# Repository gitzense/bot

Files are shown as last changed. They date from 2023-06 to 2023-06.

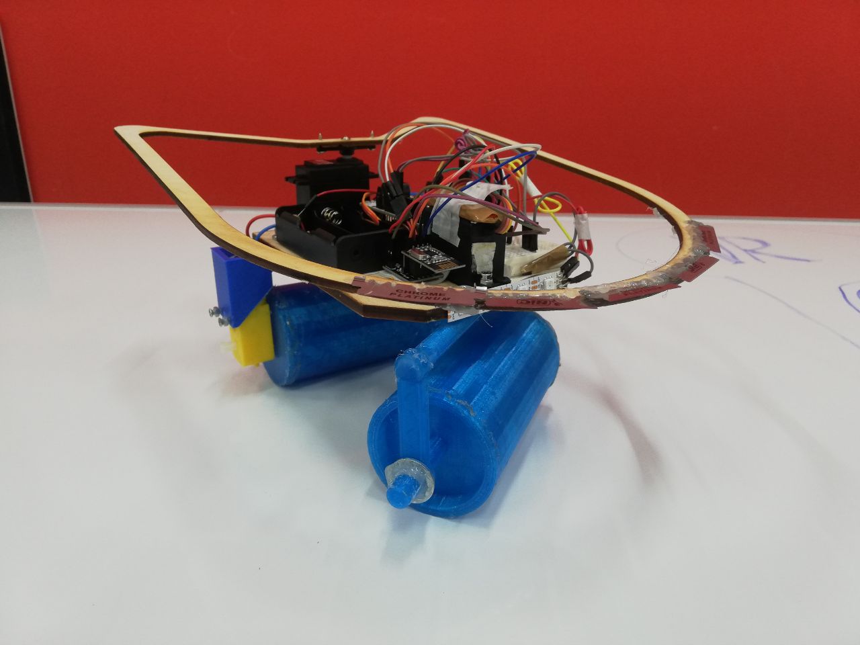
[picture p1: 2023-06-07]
photos and videos/bot_7.jpg

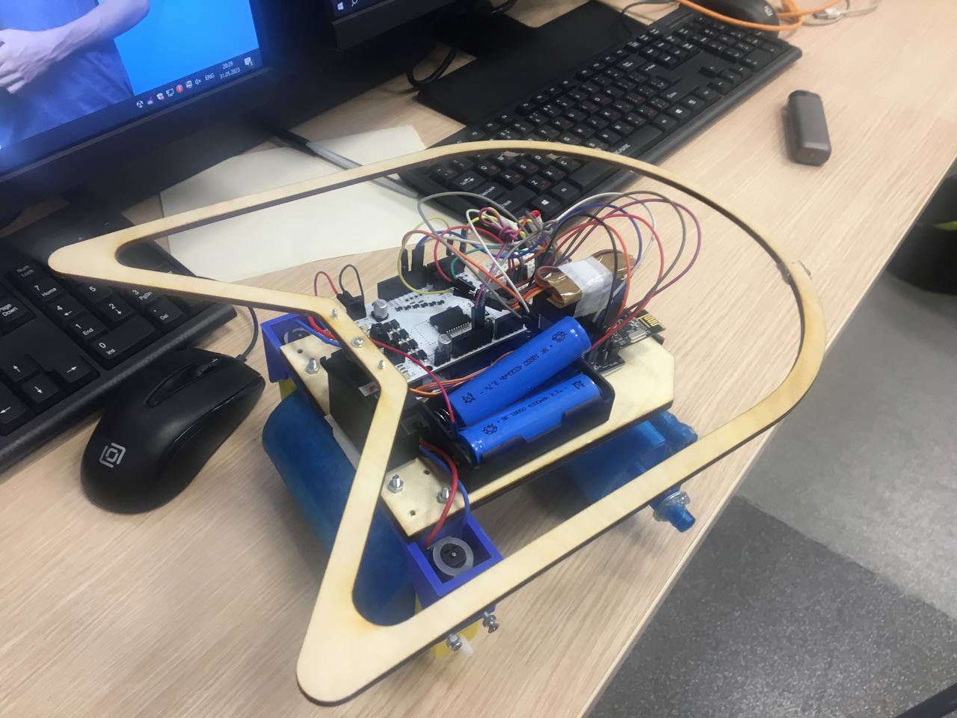
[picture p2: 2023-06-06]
photos and videos/bot_3.jpg

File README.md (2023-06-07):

# Робот на ардуино
Бот был протестирован на трассе. Время прохождения трассы - 1 минута 34 секунды. Пройдены 4/4 испытаний.

track

Робот на Arduino Leonardo с радиомодулем NRF24. Для лучшего сцепления с гладкой поверхностью на ходовые валки был нанесен термоклей вдоль оси движение в небольшом количестве.

bot_6

В роботе использовалось:
- Motor Shield,
- Arduino Leonardo/Amperka Iskra Neo,
- NRF,
- NRF+,
- акумуляторы 18650 x2,
- DC motor x2,
- RGB LED лента (4 светодиода),
- servo 180 x2.

https://github.com/gitzense/bot/assets/114235388/fd15c5e6-877d-4c51-bf17-9566ea2b325a

Для контроллера использовалась плата Arduino Pro Micro. Джойствик отвечал за движение по оси Y, потенциометр управлял сервоприводом для поворота, кнопка отвечала за движение сервопривода с режущей насадкой. 

controller

В контроллере использовалось:
- Arduino Pro Micro,
- NRF,
- NRF+,
- повербанк,
- потенциометр,
- кнопка,
- джойстик.

https://github.com/gitzense/bot/assets/114235388/252602ba-0840-4733-84bb-086d04a6e93f

Использованные библиотеки:
- Servo by Michael Margolis (управление сервоприводами),
- Adafruit NeoPixel by Adafruit (настройка светодиодной ленты),
- RF24 by TMRh20 (управление радиомодулем).

1. Код для контроллера:

``` c++
#include <SPI.h>
#include <nRF24L01.h>
#include <RF24.h>

#define VX_PIN A0
#define VY_PIN A1
#define BTN_PIN 2

RF24 radio(9, 10);
int data[3];

void setup() {

  Serial.begin(9600);
  radio.begin();
  radio.setChannel(2);
  radio.setDataRate(RF24_1MBPS);
  radio.setPALevel(RF24_PA_HIGH);
  radio.openWritingPipe(0x1234567890LL);
  radio.stopListening();
  
  pinMode(BTN_PIN, INPUT);
  
}

void loop() {

  data[0] = analogRead(VX_PIN);
  data[1] = analogRead(VY_PIN);
  data[2] = digitalRead(BTN_PIN);

  radio.write(&data, sizeof(data));
  delay(15);
  
}
```

2. Код для робота:

``` c++
#include <SPI.h>
#include <nRF24L01.h>
#include <RF24.h>

#include <Adafruit_NeoPixel.h>

#include <Servo.h>
Servo myservo;
Servo myservo2;

#define SPEED_1 5 
#define DIR_1 4

#define SPEED_2 6
#define DIR_2 7

#define MATRIX_PIN    0
#define LED_COUNT 4

Adafruit_NeoPixel matrix = Adafruit_NeoPixel(LED_COUNT, MATRIX_PIN, NEO_GRB + NEO_KHZ800);

RF24 radio(9, 10);
int data[3];

int pos = 15;

void setup() {
  
  Serial.begin(9600);
  myservo.attach(3);
  myservo2.attach(12);
  matrix.begin();
  radio.begin();
  radio.setChannel(2);
  radio.setDataRate(RF24_1MBPS);
  radio.setPALevel(RF24_PA_HIGH);
  radio.openReadingPipe(0, 0x1234567890LL);
  radio.startListening();

  for (int i = 4; i < 8; i++) {     
    pinMode(i, OUTPUT);
  }
  
}

void loop() { 
  
  if (radio.available()) {
    radio.read(&data, sizeof(data));

    for (int i = 0; i < matrix.numPixels(); i++) {
      matrix.setPixelColor(i, 255, 255, 255);
      matrix.show();  
    }

    int servoPosition = map(data[0], 0, 1023, 0, 180);
    myservo.write(servoPosition);

    if (data[2] == 1) {
      myservo2.write(45);
      pos = 15;
    }  
    else if (data[2] == 0) {
      myservo2.write(pos);
      pos += 1;
      if (pos == 75) {
        pos = 15;
      }
    }
    if (data[1] < 200) {
      digitalWrite(DIR_1, HIGH);
      digitalWrite(DIR_2, HIGH);
      analogWrite(SPEED_1, 220);
      // analogWrite(SPEED_2, 220);
     }
    else if (data[1] > 900) {
      digitalWrite(DIR_1, LOW);
      digitalWrite(DIR_2, LOW);
      analogWrite(SPEED_1, 255);
      analogWrite(SPEED_2, 255);
    }
    else {
      digitalWrite(DIR_1, HIGH);
      digitalWrite(DIR_2, LOW);
      analogWrite(SPEED_1, 0);
      analogWrite(SPEED_2, 0);      
    }
  }
  
}
```

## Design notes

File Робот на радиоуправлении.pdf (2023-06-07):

МИНИСТЕРСТВО ОБРАЗОВАНИЯ И НАУКИ РОССИЙСКОЙ ФЕДЕРАЦИИ

ФЕДЕРАЛЬНОЕ ГОСУДАРСТВЕННОЕ АВТОНОМНОЕ УЧРЕЖДЕНИЕ ВЫСШЕГО ОБРАЗОВАНИЯ

«Национальный исследовательский технологический

университет «МИСиС»

ИНСТИТУТ | ЭКОТЕХНОЛОГИЙ И ИНЖИНИРИНГА
КАФЕДРА | МЕТАЛЛОВЕДЕНИЕ ЦВЕТНЫХ МЕТАЛЛОВ
НАПРАВЛЕНИЕ | 15.04.02 Технологические машины и оборудование

Практика цифрового производства

на тему: “Робот на радиоуправлении”

Студент: Фролов Н.В.

Группа: МТМО-22-3

Проверил: Тавитов А.Г.

Москва 2023

Содержание

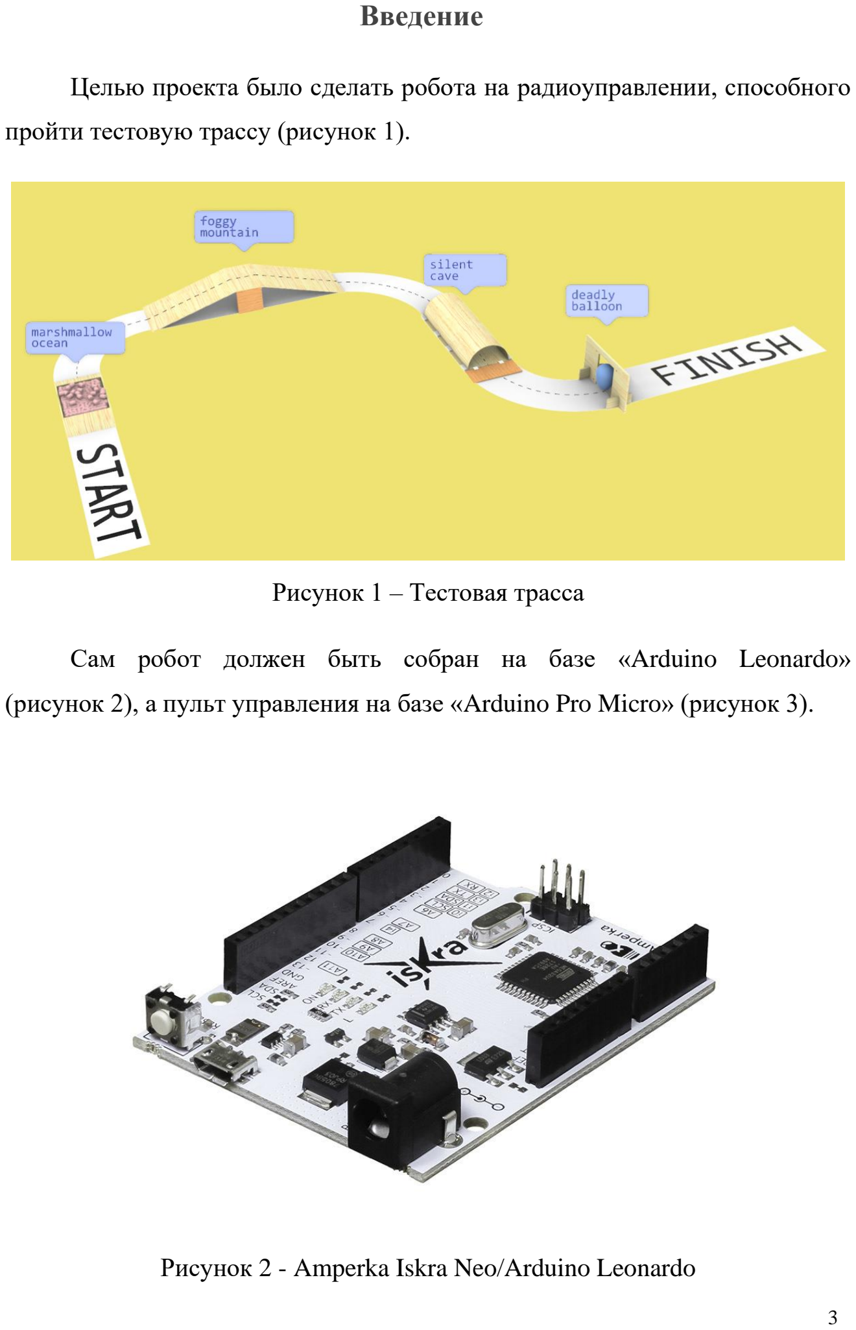
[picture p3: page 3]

Введение

Целью проекта было сделать робота на радиоуправлении, способного

пройти тестовую трассу (рисунок 1).

Рисунок 1 – Тестовая трасса

Сам робот должен быть собран на базе «Arduino Leonardo»

(рисунок 2), а пульт управления на базе «Arduino Pro Micro» (рисунок 3).

Рисунок 2 - Amperka Iskra Neo/Arduino Leonardo

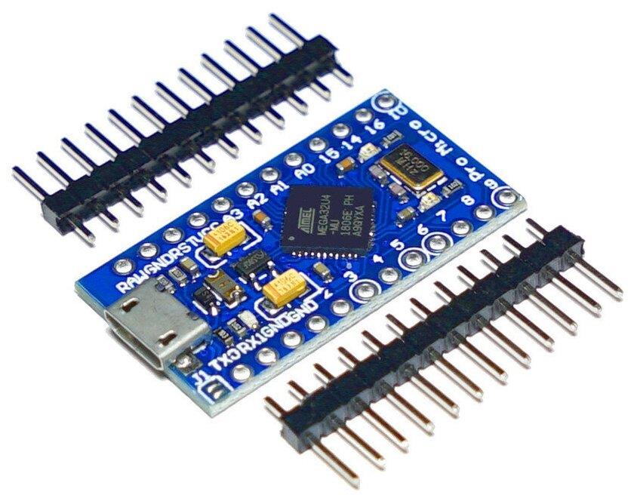
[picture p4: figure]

Рисунок 3 - Arduino Pro Micro

Дополнительным условием было: «робот должен передвигаться не на

колесах».

### 1 Работа над роботом

### 1.1 Компоненты

Изначально были даны следующие компоненты:

- Arduino Leonardo/Amperka Iskra Neo,
- Motor Shield,
- NRF,
- NRF+,
- Аккумуляторы 18650 x2,
- DC motor x2,
- RGB LED лента (4 светодиода),
- Servo 180 x2.

### 1.2 Проектирование и печать

Было принято решение, что робот будет передвигаться при помощи

двух валков, референсом был дорожный каток (рисунок 4).

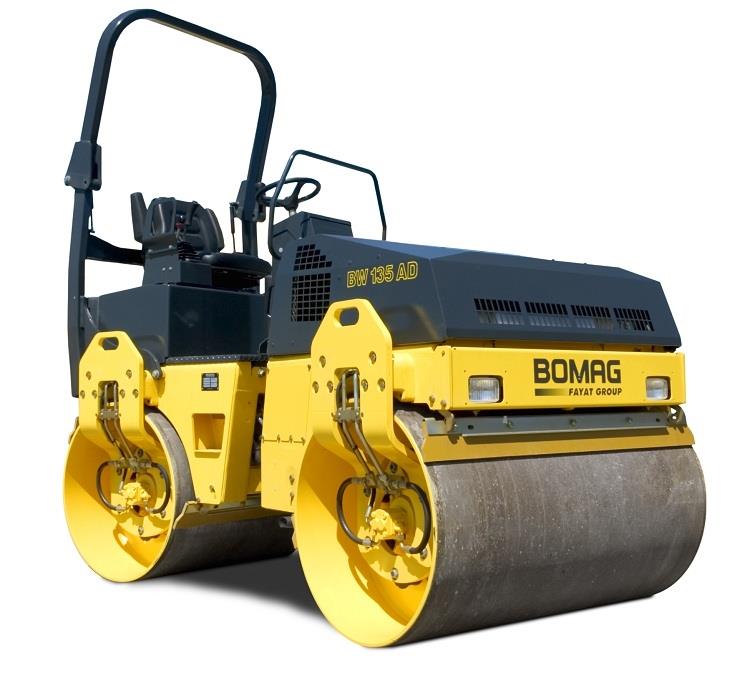
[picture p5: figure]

Рисунок 4 – Дорожный каток

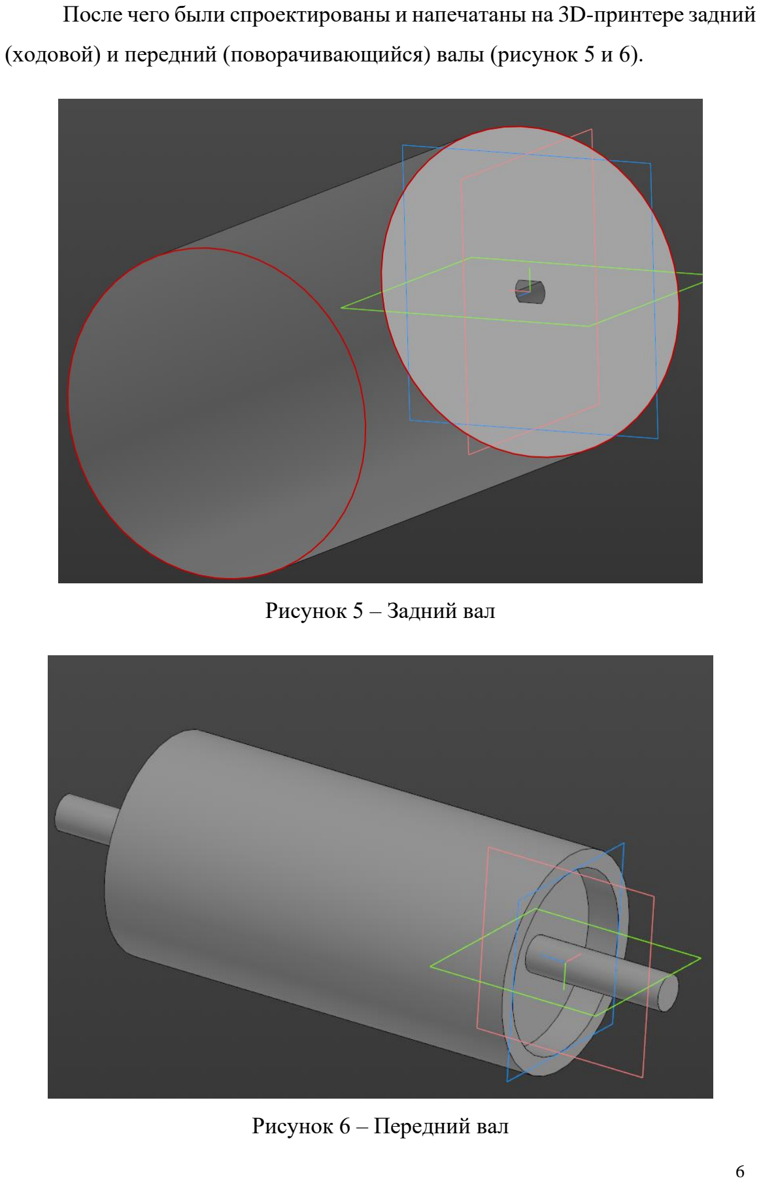
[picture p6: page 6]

После чего были спроектированы и напечатаны на 3D-принтере задний

(ходовой) и передний (поворачивающийся) валы (рисунок 5 и 6).

Рисунок 5 – Задний вал

Рисунок 6 – Передний вал

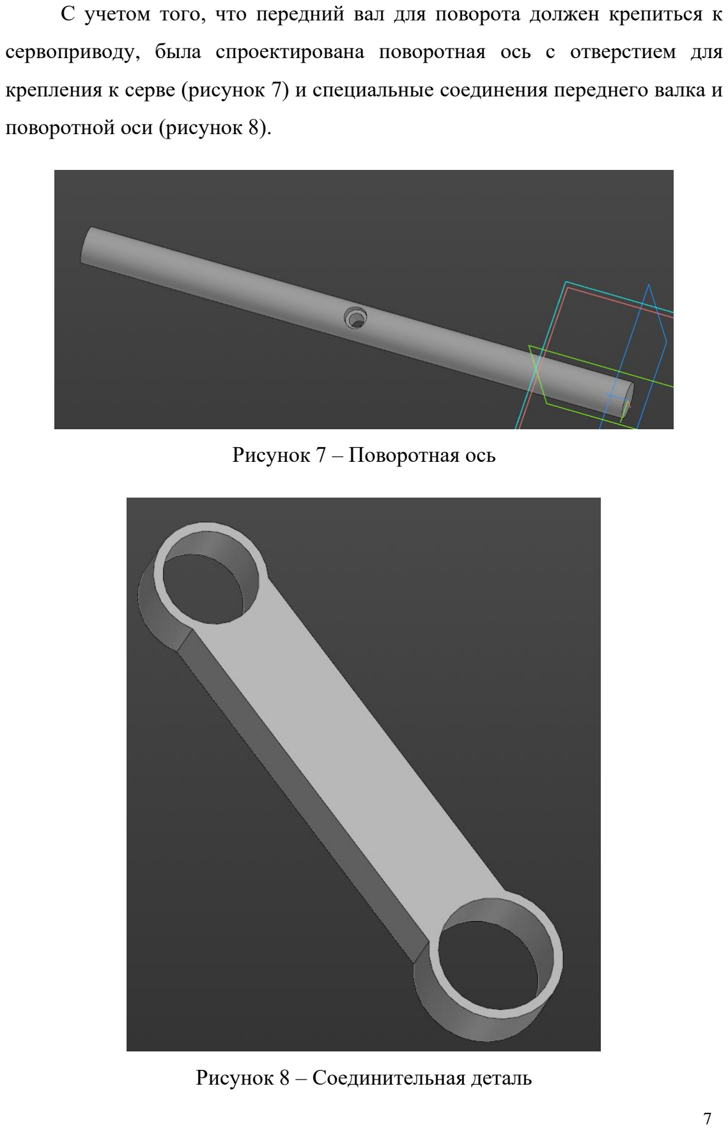
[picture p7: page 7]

С учетом того, что передний вал для поворота должен крепиться к

сервоприводу, была спроектирована поворотная ось с отверстием для

крепления к серве (рисунок 7) и специальные соединения переднего валка и

поворотной оси (рисунок 8).

Рисунок 7 – Поворотная ось

Рисунок 8 – Соединительная деталь

Для крепления моторов к роботу были спроектированы и напечатаны

кронштейны (рисунок 9).

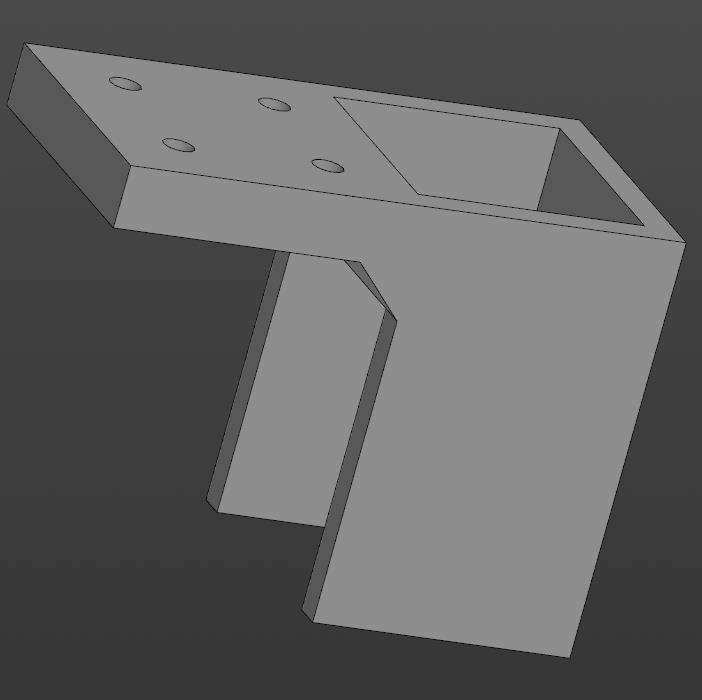
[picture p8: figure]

Рисунок 9 - Кронштейн

### 1.3 Лазерная резка

Было принято решение, что основа робота, на которой будут

закреплены все элементы, не должна быть слишком громоздкой. В связи с

этим, габариты основы подбирались так, чтобы все компоненты сидели

почти вплотную. Сама основа в дальнейшем была вырезана на лазерном

станке (рисунок 10).

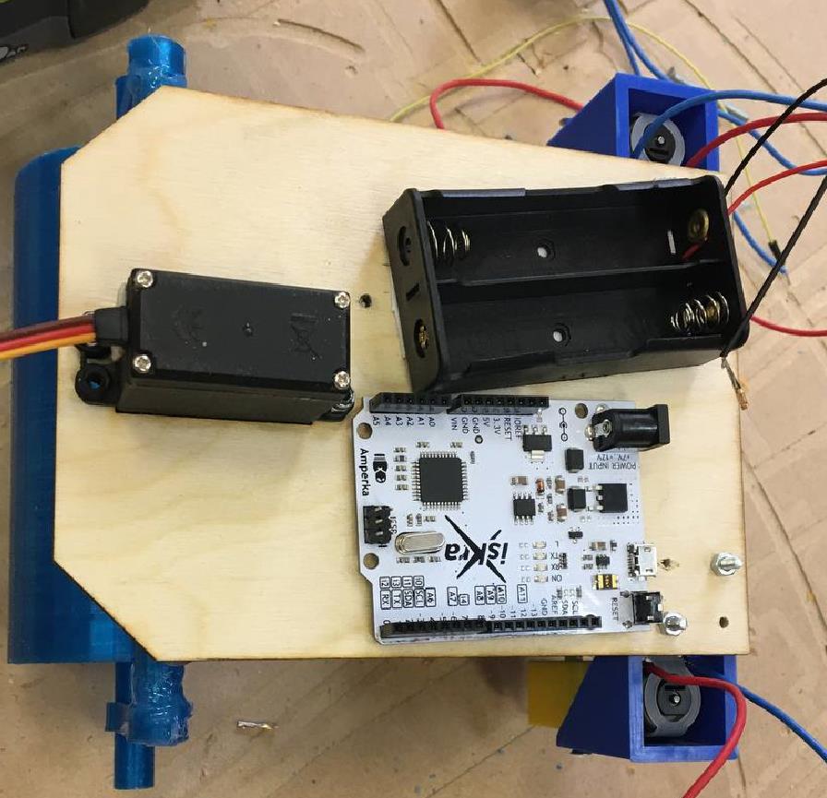
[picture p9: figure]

Рисунок 10 – Установленная основа

Так как на тестовой трассе необходимо лопнуть шарик, дополнительно

была сделана деталь (рисунок 11), на которой в дальнейшем были

закреплены лезвия. Габариты детали выбирались исходя из основы робота,

режущая часть должна выступать вперед более чем на 50 мм. Весь

получившийся «резак» был закреплен на сервоприводе.

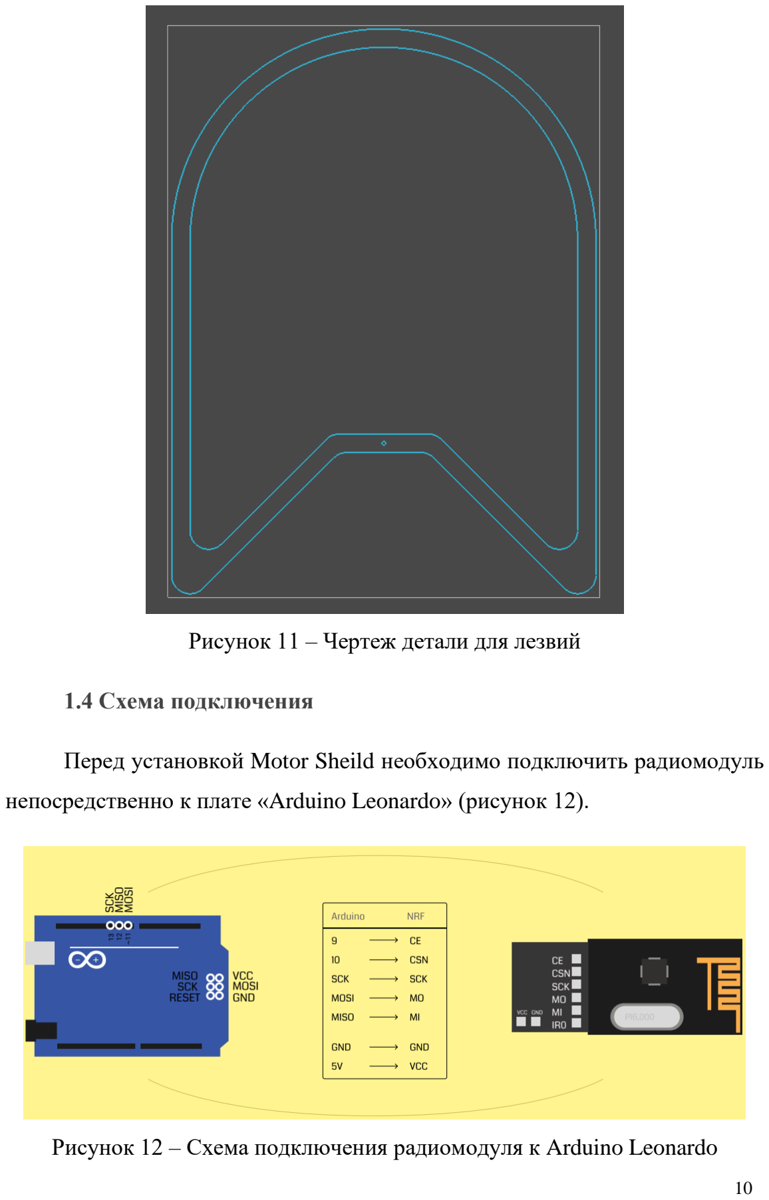
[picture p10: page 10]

Рисунок 11 – Чертеж детали для лезвий

### 1.4 Схема подключения

Перед установкой Motor Sheild необходимо подключить радиомодуль

непосредственно к плате «Arduino Leonardo» (рисунок 12).

Рисунок 12 – Схема подключения радиомодуля к Arduino Leonardo

Затем на плату устанавливается Motor Sheild, и через breadboard все

компоненты подключаются к связке «motor shield-плата» (рисунок 13).

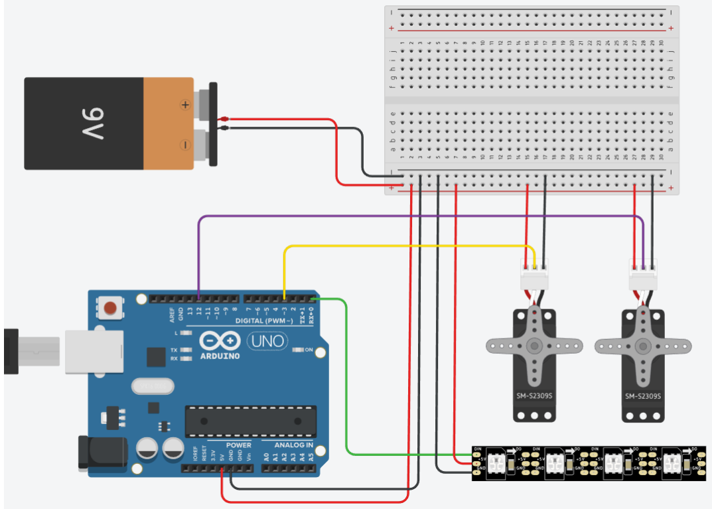
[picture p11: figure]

Рисунок 13 – Схема подключения компонентов к роботу

### 2 Работа над пультом управления

### 2.1 Компоненты

- Arduino Pro Micro,
- Потенциометр,
- NRF,
- NRF+,
- Кнопка,
- Джойстик.

### 2.2 Лазерная резка

Для удобства использования всех компонентов, была вырезана основа

пульта (рисунок 14), на которой были закреплены все элементы управления

(рисунок 15).

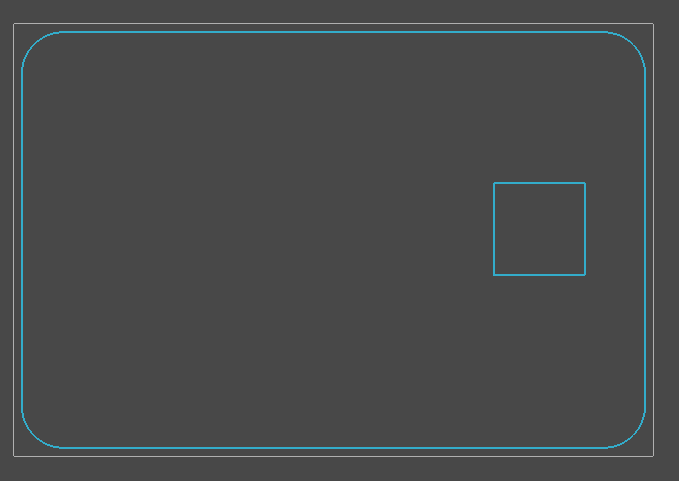
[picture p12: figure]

Рисунок 14 – Чертеж основы для пульта управления

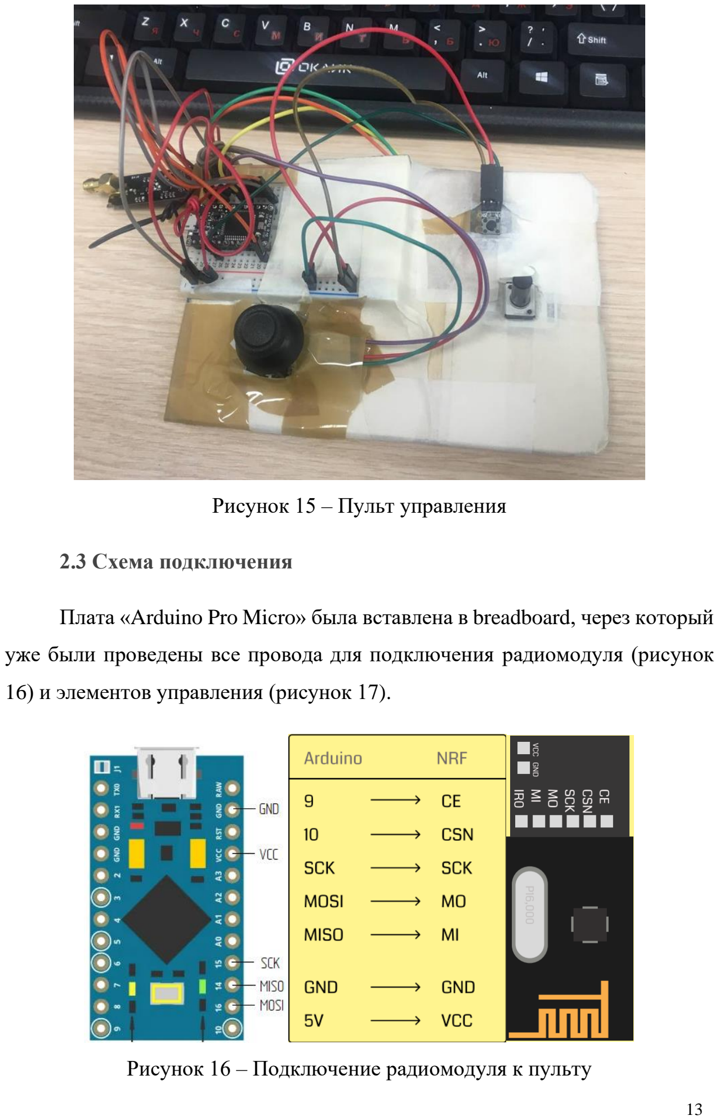
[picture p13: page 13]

Рисунок 15 – Пульт управления

### 2.3 Схема подключения

Плата «Arduino Pro Micro» была вставлена в breadboard, через который

уже были проведены все провода для подключения радиомодуля (рисунок

16) и элементов управления (рисунок 17).

Рисунок 16 – Подключение радиомодуля к пульту

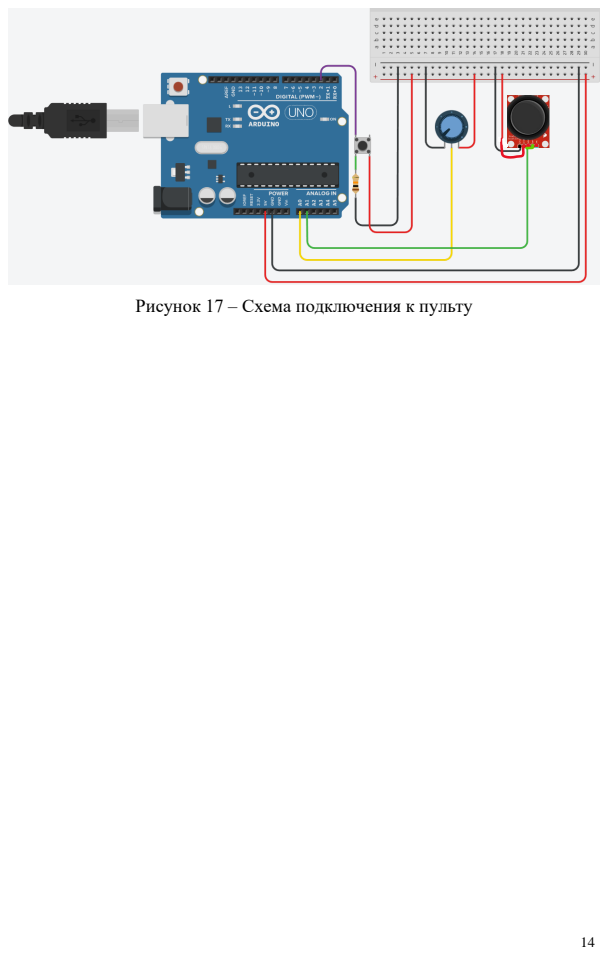
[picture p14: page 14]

Рисунок 17 – Схема подключения к пульту

### 3 Код

Для управления был написан код для основной платы робота:

приемника (рисунок 18) и для пульта управления: передатчика

(рисунок 19).

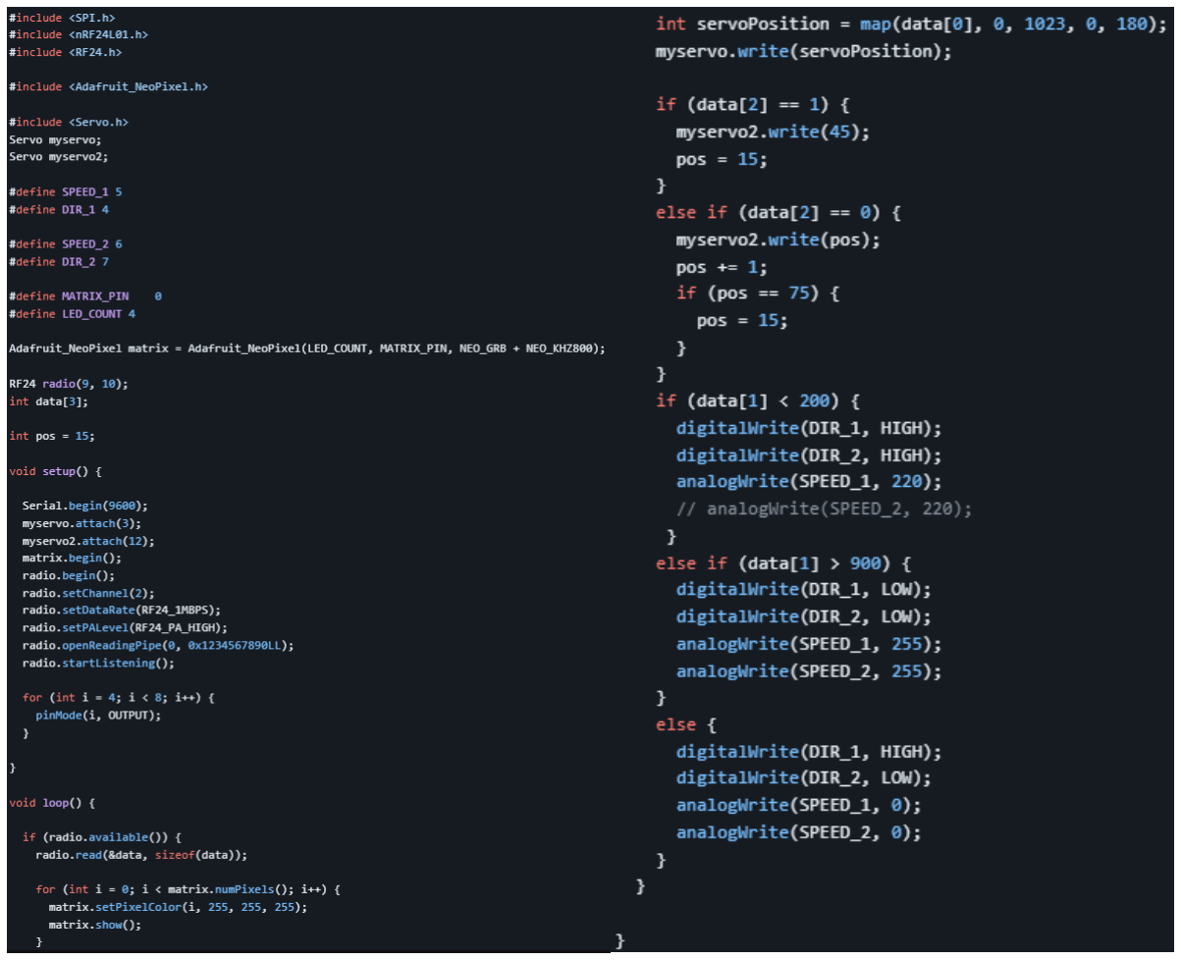
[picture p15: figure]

Рисунок 18 – Код для приемника

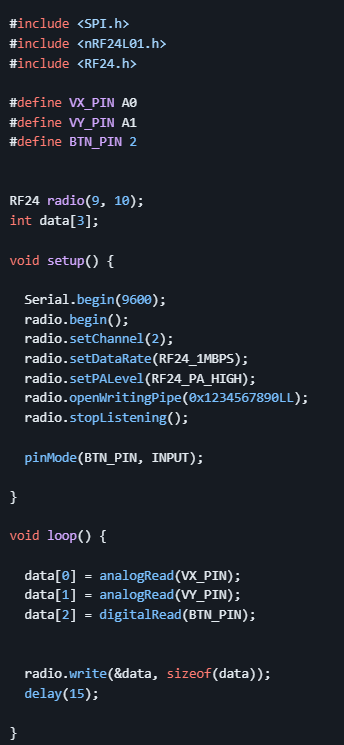
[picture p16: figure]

Рисунок 19 – Код для передатчика

### 4 Проблемы и решения

Первой проблемой стал «гуляющий» передний валок при повороте.

Эта проблема возникла из-за особенности соединения валка и поворотной

оси. Поскольку нижнее отверстие соединения должно быть большего

диаметра, чтобы валок мог крутиться, из-за этого же сам вал при повороте

иногда проскальзывал по этому отверстию.

Несмотря на то, что эта проблема никак не сказывалась на

работоспособности, возникли опасения, что при резком повороте может

повредиться либо само соединение, либо сервопривод, поэтому было

принято решение ограничить движение валка в отверстии соединения

шайбами (рисунок 20).

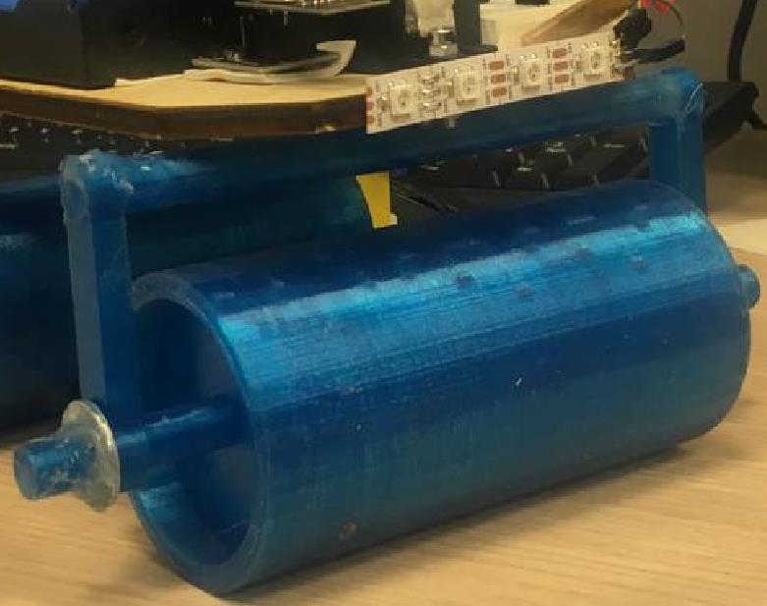
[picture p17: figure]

Рисунок 20 – Решение первой проблемы

Второй проблемой стали стенки кронштейнов. Они терлись о ходовой

валок, потому было принято решение их подрезать (рисунок 21).

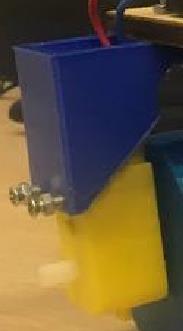
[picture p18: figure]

Рисунок 21 – Решение второй проблемы

Третья проблема – плохо прилегающий «плюс» в аккумуляторном

блоке, поэтому плюс проведен отдельным проводом (рисунок 22).

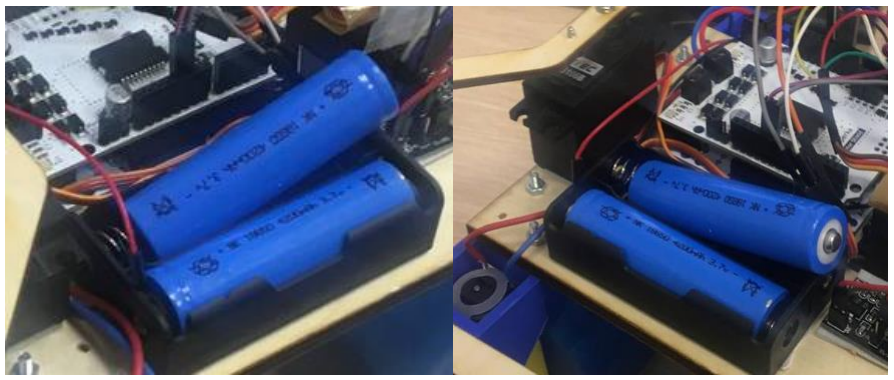
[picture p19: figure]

Рисунок 22 – Решение третьей проблемы

Четвертая проблема состояла в том, что элементы управления плохо

садились на стяжки, в связи с этим все было закреплено на скотч и ленту

(см. рисунок 15).

Последняя проблема обнаружилась при тренировочном прохождении

трассы – валки слишком гладкие и им не хватало сцепления для подъема в

горку. Чтобы решить эту проблему на валки был нанесен термоклей в

небольшом количестве вдоль оси движения. Сцепление на горке

улучшилось, но скорость на обычном покрытии сильно упала, что

неприятно, но не столь критично.

Заключение

В ходе выполнения проекта были спроектированы и сделаны

необходимые для робота детали, написан код для управления роботом,

сделан пульт управления.

Робот был собран и протестирован перед заездом. Передача сигнала и

все заложенные функции работают.

Тестовую трассу робот полностью прошел.

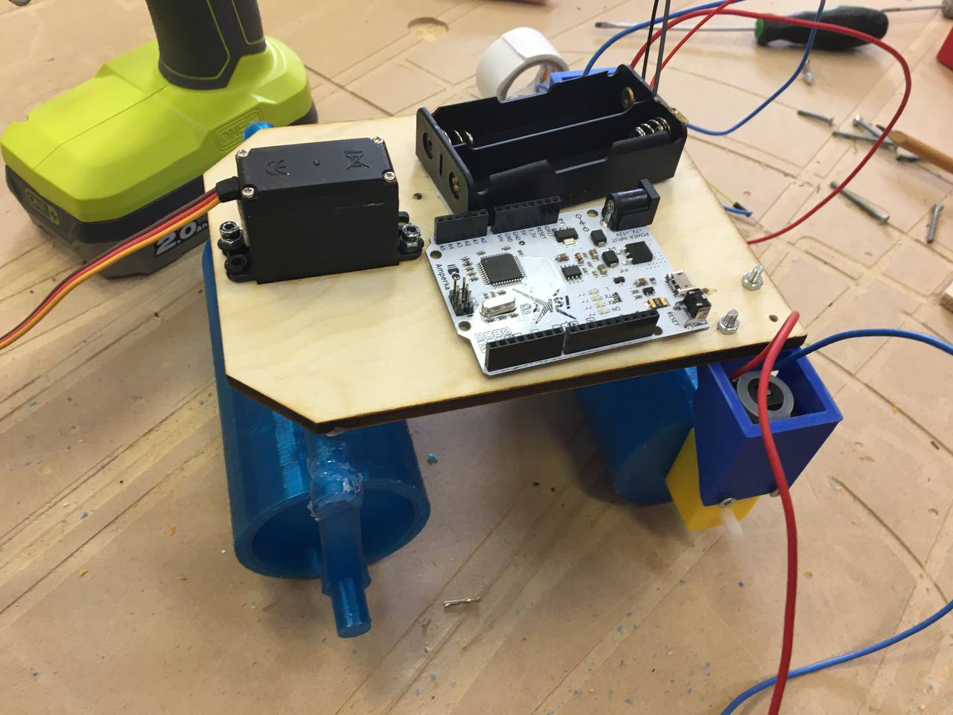
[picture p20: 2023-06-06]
photos and videos/bot_in_progress_1.jpg

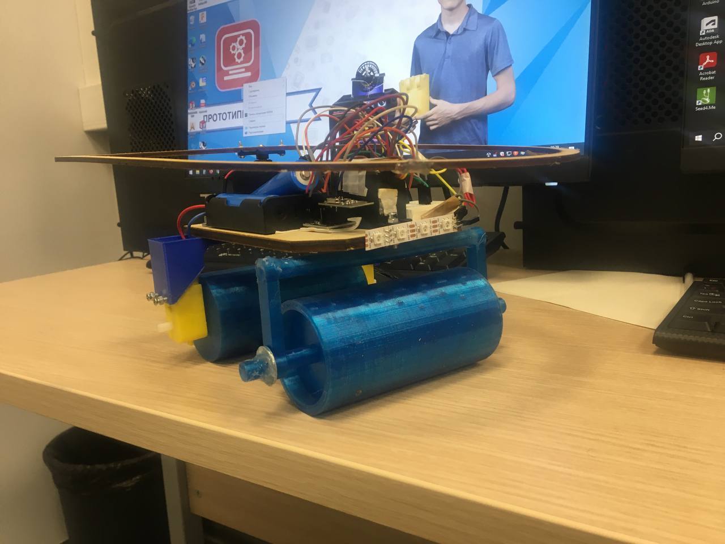
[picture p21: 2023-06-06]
photos and videos/bot_1.jpg

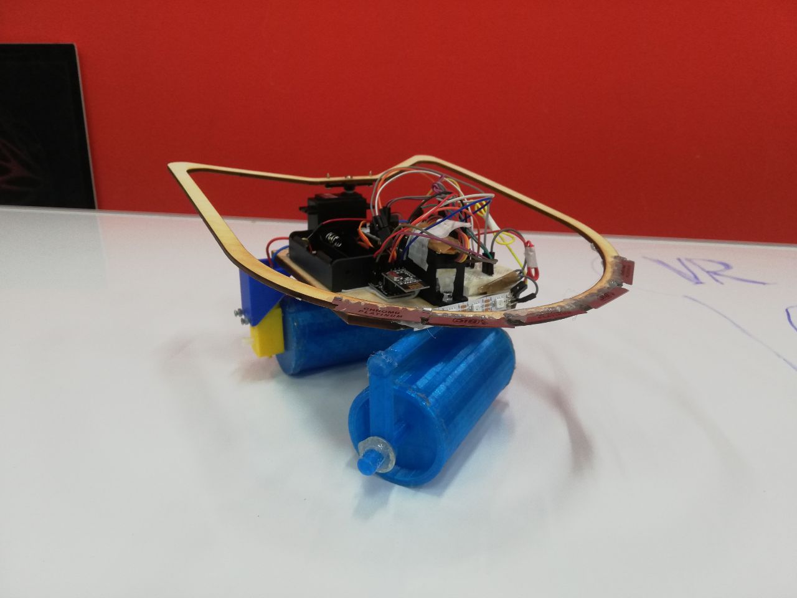
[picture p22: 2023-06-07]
photos and videos/bot_5.jpg

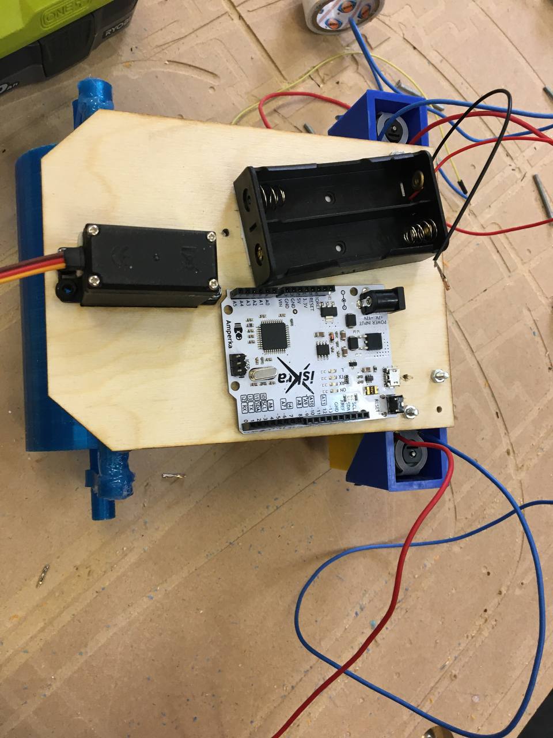
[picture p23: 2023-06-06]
photos and videos/bot_in_progress_2.jpg

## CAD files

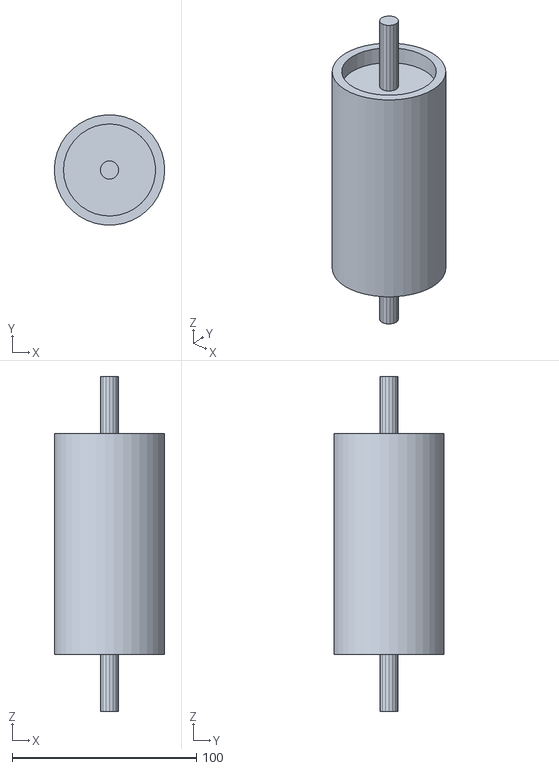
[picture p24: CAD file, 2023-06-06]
STL/front shaft.stl
60.0 x 59.8 x 182.0

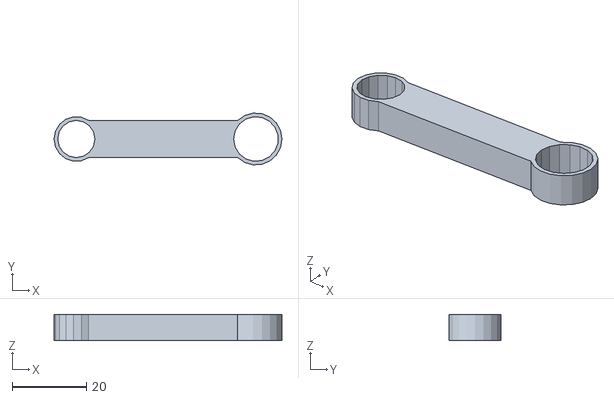
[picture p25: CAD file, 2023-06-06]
STL/shafts connector.stl
61.3 x 13.9 x 7.00

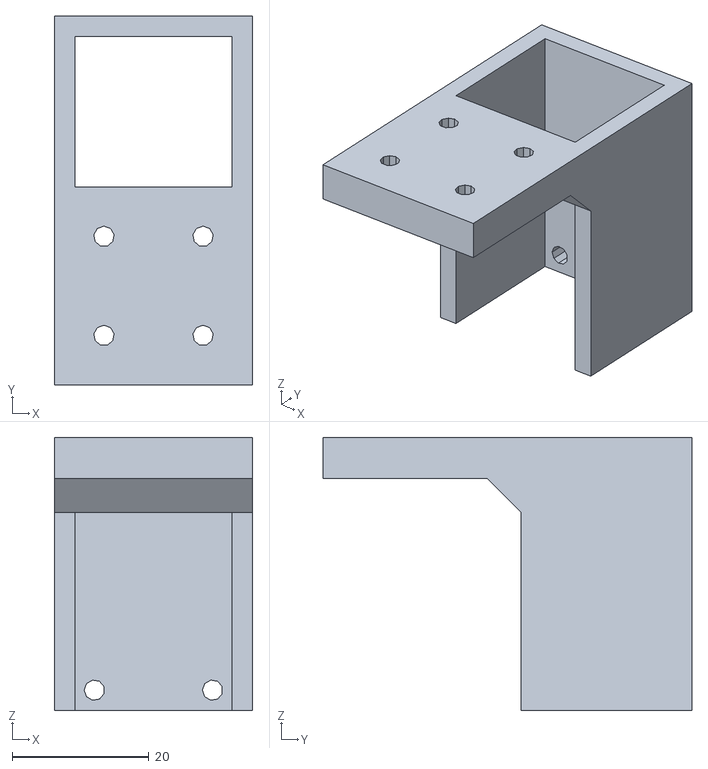
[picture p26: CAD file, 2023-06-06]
STL/engine bracket.stl
29.0 x 54.0 x 40.0

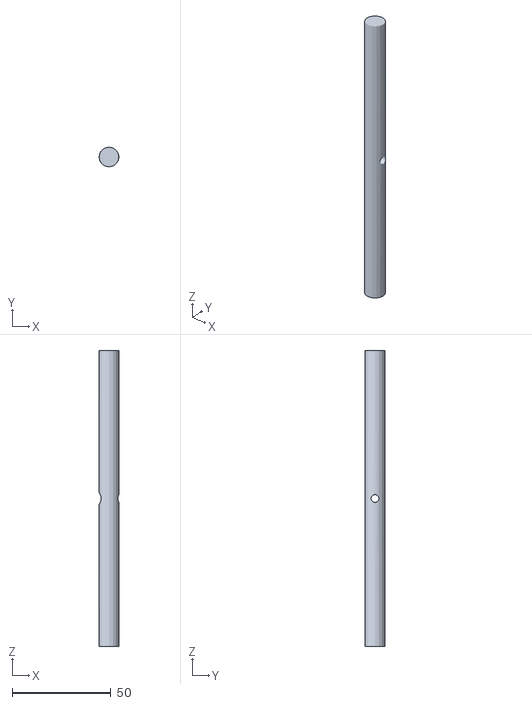
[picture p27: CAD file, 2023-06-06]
STL/rotary shaft.stl
10.0 x 10.0 x 150.0

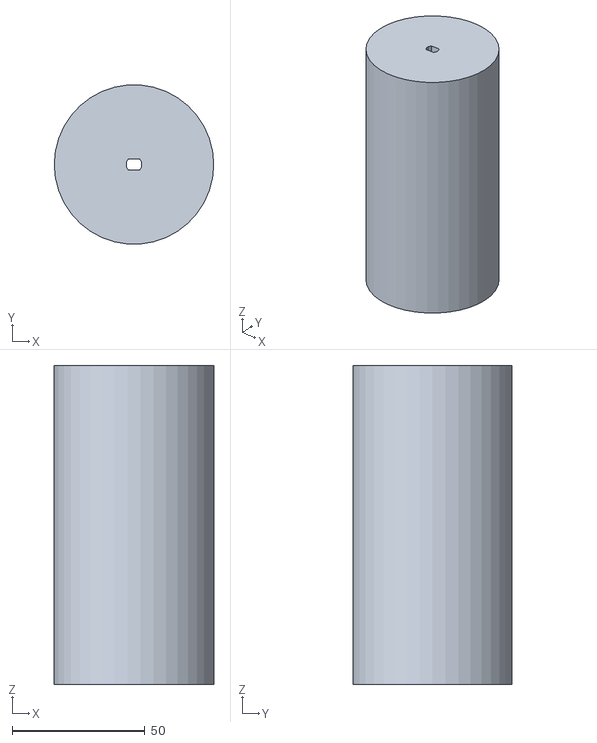
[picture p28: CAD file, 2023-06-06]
STL/back shaft.stl
60.0 x 59.8 x 120.0

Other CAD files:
cutting drawings/remote controller.dwg
cutting drawings/cutter.dwg

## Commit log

2023-06-06 all files added
    [back shaft.stl, cutter.dwg, engine bracket.stl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]
2023-06-07 report and code correction
    [bot.ino, controller.ino]
